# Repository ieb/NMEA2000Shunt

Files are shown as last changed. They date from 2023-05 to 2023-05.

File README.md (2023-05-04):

# Nmea2000 Battery Sensor.

Mk1 used the ADC on an Attiny3224. Fine for voltage but not really accurate enough for low levels of current on a 75mV 100A shunt. 

This version is built arround a INA219 which is far easier to use. It speaks CAN to communicate with a NMEA2000 bus.

A BLE version was created, but in the end I felt it was overcomplicated and would need to deep sleep to avoid draining the battery.

A Modbus version was also created, but since it adds annother bus I decided to rebuild as a NMEA2000 device using the SmallNMEA2000 library that was used in the CanPressure sensor and EngineManagement modules. Both have been in service for 2 years with no issues.

# megaTinyCore 

This code needs megaTiny core 2.6.4 to work as there are some timing bugs that cause it to fail with the default platform IO 2.5.11 version. Upgrading is a pain as it requires installing a custom package. Installs from github fail as the layout of the source repo is wrong and missing files. 

The hacky way is to install manually as its not possible to install from a git repo due to a bug in the pio code that parses versions numbers.

		cd ~/src
		git clone https://github.com/SpenceKonde/megaTinyCore.git
		cd megaTinyCore
		git co -b 2.6.4
		mkdir ~/.platformio/packages/framework-arduino-megaavr-megatinycore@2.6.4
		cd ~/.platformio/packages/framework-arduino-megaavr-megatinycore@2.6.4
		cat << EOF > .piopm
		{"type": "tool", "name": "framework-arduino-megaavr-megatinycore", "version": "2.6.4", "spec": {"owner": "platformio", "id": 11448, "name": "framework-arduino-megaavr-megatinycore", "requirements": null, "uri": null}}
		EOF
		cat << EOF > package.json
		{
		  "name": "framework-arduino-megaavr-megatinycore",
		  "version": "2.6.4",
		  "description": "Arduino Wiring-based Framework for Microchip tinyAVR 0-series and 1-series chips (megaTinyCore)",
		  "keywords": [
		    "framework",
		    "arduino",
		    "microchip",
		    "tinyAVR"
		  ],
		  "repository": {
		    "type": "git",
		    "url": "https://github.com/ieb/megaTinyCore"
		  }
		}
		EOF
		ln -s ~/megaTinyCore/megaavr/* .
		ln -s ~/megaTinyCore/ChangeLog.md .
		ln -s ~/megaTinyCore/Installation.md .
		ln -s ~/megaTinyCore/MakeUPDIProgrammer.md .
		ln -s ~/megaTinyCore/README.md .
		ln -s ~/megaTinyCore/Wiring.md .

# Oled display

There is a i2c header but at this time the oled display was removed as it served minimal purpose and consumes more current.

# LED status

normal operation is on for 250ms, off for 6s. Error states are indetified by a number of 250ms flashes followed by on for 3s off for 3s.

## Key

* ^ == short flash 
* -3s- == 3s on for 3s
* _3s_ off for 3s. 
* Cycle repeats after 6s

| flashes | condition |
|---|---|
| ^ | normal |
| ^^ -3s- | INA219 chip failure |
| ^^^ -s3- | Can bus not connected or failing to respond |
| ^^^^^ -s3-  | Both Can and INA219 failing |

# ToDo

* [x] Basic implementation, with CAN.
* [x] Average current and voltage over time period, eg 30s
* [ ] Test CAN using a CandelLite adapter.
* [x] Calibrate NTC sensors.
* [x] ~~Add 1.3 inch Oled display~~
* [x] ~~Implement current monitoring with auto scaling for different ranges using features of the INA219~~ Limited benefit see p21 Table 7
* [ ] design and make box

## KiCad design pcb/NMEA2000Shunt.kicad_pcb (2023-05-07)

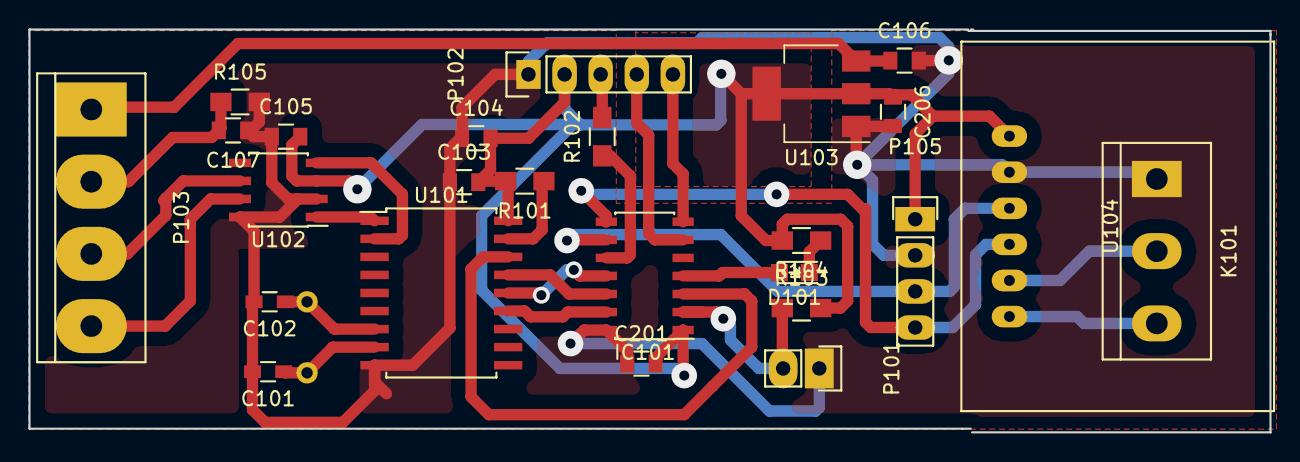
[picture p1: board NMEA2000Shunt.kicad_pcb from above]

Board: 2 copper layers, 87.3 x 28.3 mm, 26 parts (1 on the bottom side), 26 nets.

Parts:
C101, C102: 22pF; R_0603_HandSoldering
C103, C106, C206: 10uF; C_0805
C104, C105, C107, C201: 100nF; C_0805
D101: LED; LED_0805
IC101: ATTINY3224-SS; SOIC-14_3.9x8.7mm_Pitch1.27mm
K101: Battery; bornier3
P101: Temp1; Pin_Header_Straight_1x02
P102: Prog; Pin_Header_Straight_1x05
P103: CAN; bornier4
P105: OLED; Pin_Header_Straight_1x04
R101, R103, R104, R105: 10K; R_0805_HandSoldering
R102: 270R; R_0805_HandSoldering
U101: MCP2515; SOIC-18W_7.5x11.6mm_Pitch1.27mm
U102: TJA1050; SOIC-8_3.9x4.9mm_Pitch1.27mm
U103: NCP1117ST50T3G; SOT-223-3Lead_TabPin2
U104: INA219-module; INA219Module
X101: 8MHz; Resonator-2pin_w10.0mm_h5.0mm

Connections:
5V: C103.2, C104.2, C105.2, C201.2, C206.1, IC101.1, P102.2, P105.1, R101.2, R103.2, R104.2, U101.18, U102.3, U103.2, U104.1
12v: C106.1, P103.1, U103.3
CANCS: IC101.3, U101.16
CANGND: C107.2, P103.2, R105.1
CANH: P103.4, U102.7
CANL: P103.3, U102.6
GND: C101.2, C102.2, C103.1, C104.1, C105.1, C106.2, C107.1, C201.1, C206.2, IC101.14, K101.1, P101.1, P102.1, P105.2, R105.2, U101.9, U102.2, U102.8, U103.1, U104.2
IN+: K101.3, U104.6
IN-: K101.2, U104.5
LED: D101.2, IC101.4
MISO: IC101.12, U101.15
MOSI: IC101.11, U101.14
unnamed: C101.1, U101.8, X101.1
unnamed: C102.1, U101.7, X101.2
unnamed: D101.1, R104.1
unnamed: P102.3, R102.2
unnamed: R101.1, U101.17
unnamed: U101.1, U102.1
unnamed: U101.2, U102.4
RX: IC101.6, P102.4
SCK: IC101.13, U101.13
SCL: IC101.9, P105.3, U104.3
SDA: IC101.8, P105.4, U104.4
TEMP1: IC101.2, P101.2, R103.1
TX: IC101.7, P102.5
UDPI: IC101.10, R102.1

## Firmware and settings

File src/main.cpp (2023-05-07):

#include <Arduino.h>
#include <Wire.h>



#include "n2kshunt.h"
#include "commandline.h"
#include "ina219.h"
#include "config.h"
#include "ntcsensor.h"

// Hardware
// Vcc chip pin 1
#define TEMP1_PIN PIN_PA4 // chip pin 2
#define CANCS_PIN PIN_PA5 // chip pin 3
#define LED_PIN PIN_PA6 // chip pin 4
// PIN_PA7 not used       // chip pin 5
#define RX0_PIN   PIN_PB3 // chip pin 6, default
#define TX0_PIN   PIN_PB2 // chip pin 7, default
#define SDA_PIN   PIN_PB1 // chip pin 8, cant be moved.
#define SCL_PIN   PIN_PB0 // chip pin 9, cant be moved.
#define UDPI_PIN  PIN_PA0 // chip pin 10, cant be moved.
#define MOSI_PIN  PIN_PB1 // chip pin 11, default
#define MIS0_PIN  PIN_PB2 // chip pin 12, default
#define SCK_PIN   PIN_PB3 // chip pin 13, default
// GND chip pin 14

//  Check and update https://ieb.github.io/notes/ to get a clean address.
#define DEVICE_ADDRESS 26



// default serial for debug, serial 1 not used.
#define debug Serial


// configure CAN device
const SNMEA2000ProductInfo productInfomation PROGMEM={
                                       1300,                        // N2kVersion
                                       45,                         // Manufacturer's product code
                                       "Shunt",    // Manufacturer's Model ID
                                       "1.0.0.1 (2023-04-26)",     // Manufacturer's Software version code
                                       "1.0.0.2 (2023-04-26)",      // Manufacturer's Model version
                                       "0000003",                  // Manufacturer's Model serial code
                                       0,                           // SertificationLevel
                                       1                            // LoadEquivalency
};
const SNMEA2000ConfigInfo configInfo PROGMEM={
      "Battery Shunt",
      "Luna Technical Area",
      "https://github.com/ieb/NMEA2000Shunt"
};

uint8_t pgnEnableRegister = 0xff;


const unsigned long txPGN[] PROGMEM = { 
	127506L, // detailed DC status
	127513L, // battery configuration status
	127508L, // battery status message
    SNMEA200_DEFAULT_TX_PGN
};
const unsigned long rxPGN[] PROGMEM = { 
  SNMEA200_DEFAULT_RX_PGN
};

const SNMEA2000DeviceInfo devInfo = SNMEA2000DeviceInfo(
  02,   // device serial number
  170,  // Battery
  35    // Power
);



ConfigSettings settings;

Ina219 ina219(&debug);
CommandLine commandLine(&debug, &settings);
NtcSensor ntcSensor(&debug, TEMP1_PIN);


bool ina219Ok = false;
bool canOk = false;



N2kShunt n2kShunt = N2kShunt(DEVICE_ADDRESS, 
          &devInfo, 
          &productInfomation, 
          &configInfo, 
          &txPGN[0], 
          &rxPGN[0],
          CANCS_PIN
);
//          CANCS_PIN


void blink() {
	static unsigned long lastBlink = 0;
	static uint8_t led_state = 0;
	static unsigned long nextDelay = 3000;
	unsigned long now = millis();
	if ((now - lastBlink) > nextDelay ) {
		led_state = !led_state;
		digitalWrite(LED_PIN, led_state);
		if ( canOk && ina219Ok ) {
			if (!led_state) {
				// short bink dont block main thread.
				nextDelay = 250;
			} else {
				nextDelay = 6000;
			}
		} else if ( !led_state ) {
			nextDelay = 3000;
			// indicate a fault condition.
			// its ok to block the main thread as something is failing.
			// 3 flashes = can fail.
			// 2 flashes = ina219 fail.
			// 5 flashes == both failed.
			if (!canOk ) {
				for(int i = 0; i < 3; i++) {
					delay(250);
					digitalWrite(LED_PIN, HIGH);
					delay(250);
					digitalWrite(LED_PIN, LOW);
				}
			} 
			if (!ina219Ok) {
				for(int i = 0; i < 2; i++) {
					delay(250);
					digitalWrite(LED_PIN, HIGH);
					delay(250);
					digitalWrite(LED_PIN, LOW);
				}
			}
		    delay(250);
			digitalWrite(LED_PIN, HIGH);
		    delay(250);
			digitalWrite(LED_PIN, LOW);
		}
		lastBlink = millis();

	}

}



void readSensors() {
	debug.print(F(" v="));debug.print(ina219.getVoltage());
	debug.print(F(" mV c="));debug.print(ina219.getCurrent());
	double tempK = ntcSensor.getTemperature();
	debug.print(F(" A t="));debug.print(ntcSensor.getTemperature());
	debug.print(F(" K "));debug.print(ntcSensor.getTemperature()-273.15);
	debug.print(F(" C tons="));debug.print(millis());
	debug.println("");
}

void showStatus() {
	n2kShunt.dumpStatus();
}





void sendReading() {
	static unsigned long lastRead = 0;
	static uint8_t sid = 0;
	unsigned long now = millis();
	if ((now - lastRead) > 1500 ) {
		lastRead = now;
		sid++;
		double batteryTemperature = ntcSensor.getTemperature();
		double batteryVoltage = ina219.getVoltage();
		double batteryCurrent = ina219.getCurrent();
		n2kShunt.sendDCBatterStatusMessage(
			settings.config.batteryInstance,
			sid,
			batteryVoltage,
			batteryTemperature,
			batteryCurrent);
		// Not emitting Detailed DC battery status, as the calculations would almost certainly
		// be wrong. Better to rely on voltage and current and common sense.
	}
}

void sendBatteryConfigurationStatus() {
	static unsigned long lastSend = 0;
	unsigned long now = millis();
	if ((now - lastSend) > 15000 ) {
		lastSend = now;
		n2kShunt.sendBatteryConfigurationStatusMessage(
			NULL,
			settings.config.batteryInstance,
			settings.config.batteryType,
			settings.config.supportsEqualisation,
			settings.config.nominalVoltage,
			settings.config.batteryChemistry,
			settings.config.batteryCapacityAh * 3600.0,
			settings.config.batteryTemperatureCoeficient,
			settings.config.peukert,
			settings.config.chargeEfficiencyFactor);
	}		

}


bool isoRequestHandler(unsigned long requestedPGN, MessageHeader *messageHeader, byte * buffer, int len) {
	if ( requestedPGN == 127513L ) {
		n2kShunt.sendBatteryConfigurationStatusMessage(
			messageHeader,
			settings.config.batteryInstance,
			settings.config.batteryType,
			settings.config.supportsEqualisation,
			settings.config.nominalVoltage,
			settings.config.batteryChemistry,
			settings.config.batteryCapacityAh * 3600.0,
			settings.config.batteryTemperatureCoeficient,
			settings.config.peukert,
			settings.config.chargeEfficiencyFactor);		
		return true;
	}
	return false;
}





void setup() {

  // Open serial communications and wait for port to open:
  debug.begin(115200);

  pinMode(LED_PIN, OUTPUT);

  // try 115200, if that fails drop back to 9600 and set.

  debug.println(F("NMEA2000 Shunt - Booting....."));

  if ( ina219.begin() != I2C_OK) {
  	ina219Ok = false;
	debug.print(F("Failed to find INA219 chip, error:"));
	debug.println(ina219.getError());
 	debug.println(F("INA219 not responding"));
  } else {
  	ina219Ok = true;
  }

  commandLine.setCallbacks(&showStatus, &readSensors);
  commandLine.begin();




  commandLine.diagnosticsEnabled = false;


  debug.print(F("Shunt: "));
  debug.print(settings.config.shuntReading);
  debug.print(F("mV/"));
  debug.print(settings.config.shuntCurrent);
  debug.println(F("A"));
  ina219.setShutRange( settings.config.shuntReading, settings.config.shuntCurrent);

  debug.println(F("Opening CAN"));
  debug.print("CS Pin in main ");debug.println(CANCS_PIN);
  // only set on reboot.
  n2kShunt.setSerialNumber(settings.config.serialNumber);
  n2kShunt.setDeviceAddress(settings.config.deviceAddress);
  n2kShunt.setIsoRequestHandler(&isoRequestHandler);
  if ( !n2kShunt.open() ) {
  	canOk = false;
    debug.println(F("Failed to start NMEA2000, retry in 5s"));
    delay(5000);
  } else {
  	canOk = true;
  }
  debug.println(F("Opened, MCP2515 Operational"));
  debug.println(F("Running..."));
  debug.println(F("Press h for help menu"));


}




void loop() {
  static bool diagnosticsEnabled = false;
  
  if ( !canOk ) {
  	canOk = n2kShunt.open();
  };
  blink();
  sendReading();
  sendBatteryConfigurationStatus();
  n2kShunt.processMessages();
  if ( commandLine.checkCommand() ) {
  	if (!diagnosticsEnabled ) {
	  	n2kShunt.setDiagnostics(true);
	  	ina219.setDiagnostics(true);
	  	ntcSensor.setDiagnostics(true);
		diagnosticsEnabled = true;  		
  	}
  } else {
  	if ( diagnosticsEnabled ) {
	  	n2kShunt.setDiagnostics(false);
	  	ina219.setDiagnostics(false);
	  	ntcSensor.setDiagnostics(false);
		diagnosticsEnabled = false;  		
  	}

  }
}

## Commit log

2023-05-04 Initial Commit, working, can not tested
    [NMEA2000Shunt.kicad_pcb, NMEA2000Shunt.sch, _saved_NMEA2000Shunt.sch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]
2023-05-07 Working version tested with Cansocket and canboat
    [NMEA2000Shunt.kicad_pcb, _saved_NMEA2000Shunt.sch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]
2023-09-09 Fixed 49day overflows
    [NMEA2000Shunt.sch, _saved_NMEA2000Shunt.sch]
